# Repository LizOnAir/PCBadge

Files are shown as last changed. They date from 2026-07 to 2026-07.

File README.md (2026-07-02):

# Soup

Mini Soup being smack onto a PCB.

Screenshot 2026-07-02 at 9 12 54 PM

## Schematic:

Screenshot 2026-07-02 at 9 14 24 PM

## PCB layout:

Screenshot 2026-07-02 at 9 13 17 PM

made in Kicad by Liz.

## BOM:

|Designator|Footprint |Quantity|Value |LCSC Part #|
|---|---|---|---|---|
|C1 |0402 |1 |220nF | |
|D3, D4 |0402 |2 |LED |C23182 |
|L1 |Antenna_8500000x5500000mm|1 |L | |
|R1, R2 |0402 |2 |47 |C16772 |
|U2 |NT3H2111W0FHKH |1 |13.56MHz|C710403 |

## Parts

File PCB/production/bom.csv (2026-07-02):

Designator | Footprint | Quantity | Value | LCSC Part #
C1 | 0402 | 1 | 220nF
D3, D4 | 0402 | 2 | LED
L1 | Antenna_8500000x5500000mm | 1 | L
R1, R2 | 0402 | 2 | 47
U2 | NT3H2111W0FHKH | 1 | 13.56MHz | C710403

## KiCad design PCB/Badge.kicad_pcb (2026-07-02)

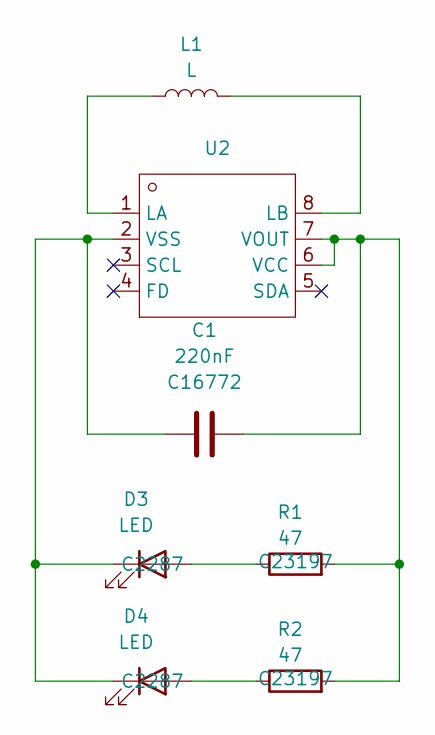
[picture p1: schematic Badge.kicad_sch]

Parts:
C1: 220nF; C_0402_1005Metric
D3, D4: LED; LED_0402_1005Metric_Pad0.77x0.64mm_HandSolder
L1: L; Antenna_8500000x5500000mm
R1, R2: 47; R_0402_1005Metric
U2: 13.56MHz; NT3H2111W0FHKH; Manufacturer Part NT3H2111W0FHKH; LCSC Part Name NT3H2111W0FHKH

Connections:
unnamed: D3.2 (A), R1.1
unnamed: C1.1, D3.1 (K), D4.1 (K), U2.2 (VSS)
unnamed: D4.2 (A), R2.1
unnamed: L1.1, U2.1 (LA)
unnamed: L1.2, U2.8 (LB)
unnamed: C1.2, R1.2, R2.2, U2.6 (VCC), U2.7 (VOUT)

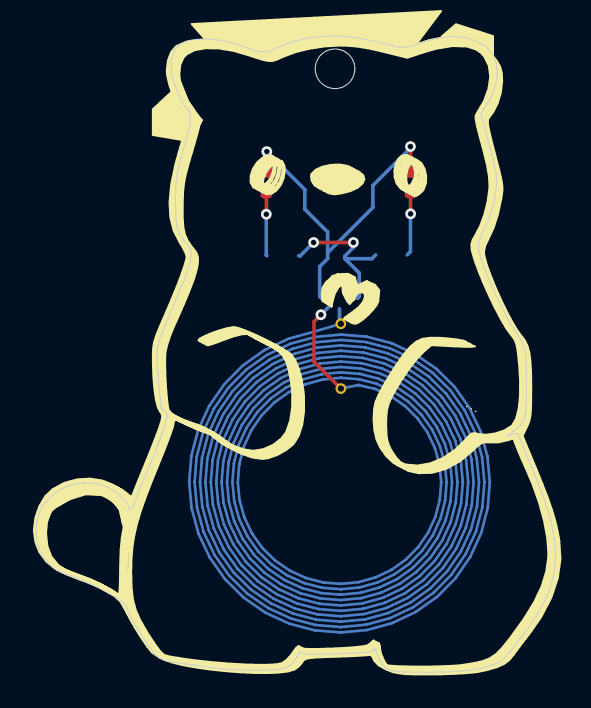
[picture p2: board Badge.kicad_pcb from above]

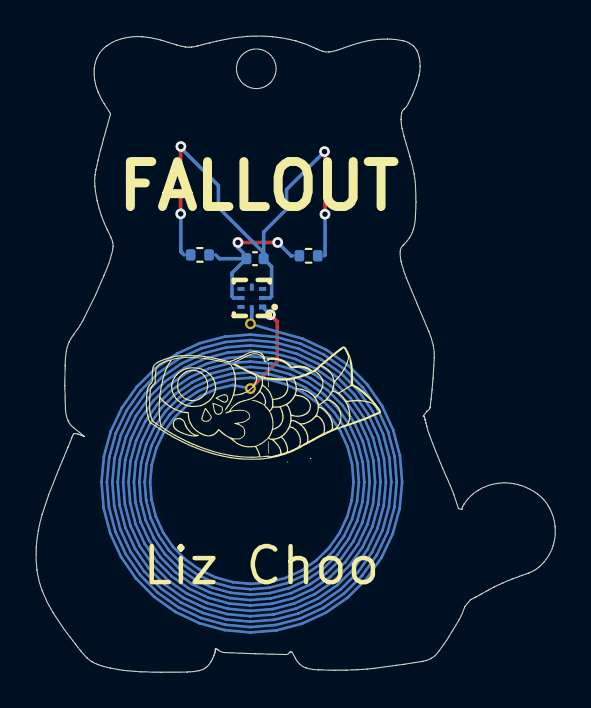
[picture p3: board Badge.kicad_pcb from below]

Board: 2 copper layers, 28.8 x 35.3 mm, 7 parts (5 on the bottom side), 6 nets.
